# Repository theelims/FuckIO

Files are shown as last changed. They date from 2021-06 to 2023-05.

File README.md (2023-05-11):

# FuckIO
An opensource fucking machine, that is far superiour to anything on the market.
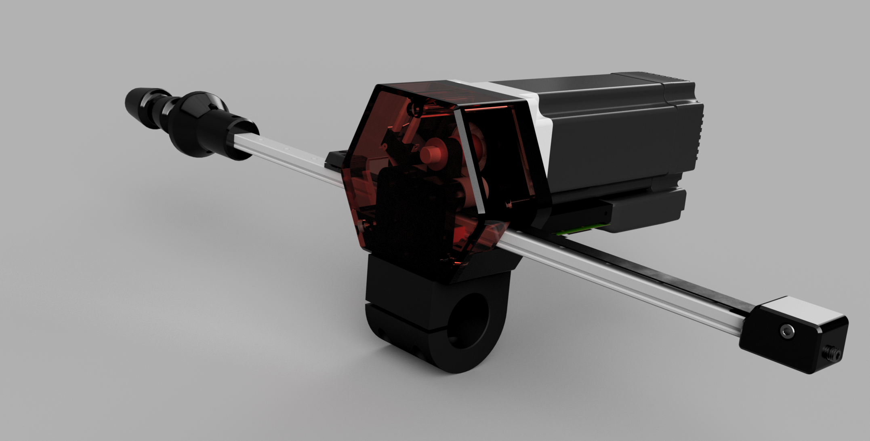
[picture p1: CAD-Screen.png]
Rendering


## Specs
* Easy to built just with a 3D-printer, screwdrivers and easy-to-source parts.
* Completely 3D-printable with easy to print parts and almost no supports. Also avoiding tight tolerances to make this accessable as possible. 
* Simple, yet verastile mechanics.
* Based on a linear position drive, not a crank mechanism.
* An 24V PWM output to drive external systems. Could be lube pumps, vibrators, etc.

## Mechanics
The mechanics is a direct derivative of an other open source project called OSSM. You can also find some informations about this build on their Discord.
https://github.com/KinkyMakers/OSSM-hardware

The motor mount is designed for a NEMA23 servo or stepper motor. Any motor fitting to this standart should work. 

### BOM
* iHSV57-30-18-36-... integrated servo motor from JMC
* 24V Power Brick Mean Well GST280A24-C6P 
* 40cm MGN12H linear rail
* 4x 605-2RS Z2 bearings
* Micro Switch
* GT2 20 Tooth Pulley for 8mm Axis and a 10mm belt
* GT2 belt with 10mm width
* Various M3 and M5 screws and nuts
* OSSM Ref Board from Research and Desire: https://shop.researchanddesire.com/collections/all/products/ossm-reference-board
* M5 Stack Remote Control from Ortlof: https://github.com/ortlof/OSSM-M5-Remote

## Control
### Firmware
The currently best firmware is the official OSSM firmware, or Ortlof's firmware for the M5 Remote https://github.com/ortlof/OSSM-M5-Remote

The firmware in the repository can only be used in conjunction with node-red.

The firmware uses the following projects:
* IotWebConf for WiFi provisioning: https://github.com/prampec/IotWebConf. Check the [end-user manual](https://github.com/prampec/IotWebConf/blob/master/doc/UsersManual.md) on how to use it.
* MQTT for communication: https://github.com/256dpi/arduino-mqtt Albeit SSL is not supported.
* My own library for generating the stroking motion: https://github.com/theelims/StrokeEngine/
* Which in turn uses https://github.com/gin66/FastAccelStepper for step generation and interfacing the servo motor.

### node-red
I've setup a node-red instance on my NAS to control FuckIO through MQTT messages. Have a look at the provided [flows.json](node-red/flows.json) to draw some inspiration from.

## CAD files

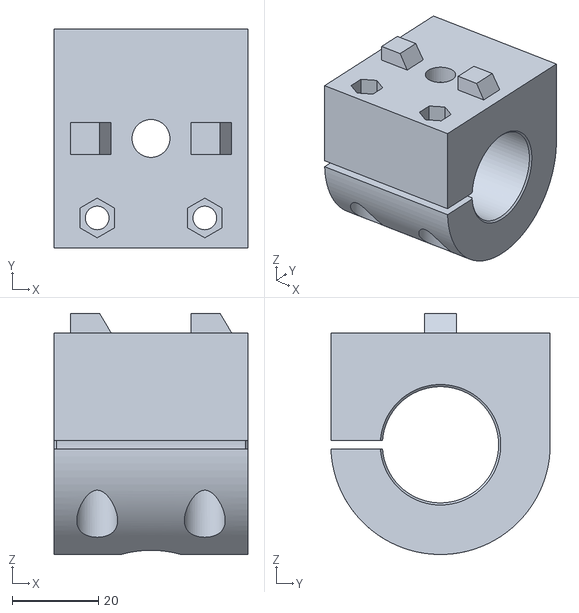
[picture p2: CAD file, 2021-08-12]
hardware/mechanics/3_4in Pipe Clamp.stl
45.0 x 51.0 x 56.0

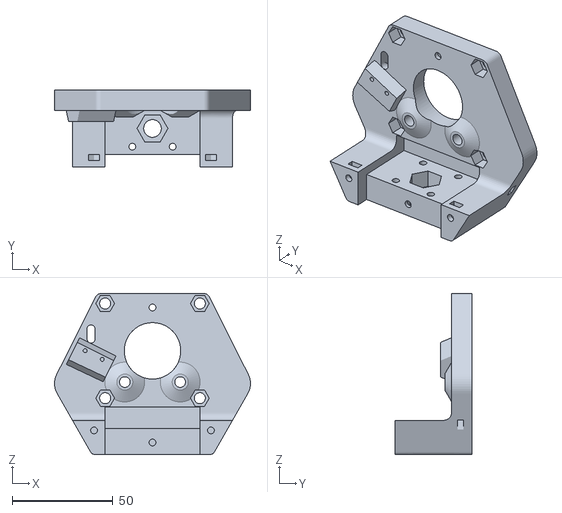
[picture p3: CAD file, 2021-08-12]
hardware/mechanics/Motor Mount.stl
97.3 x 38.0 x 80.0

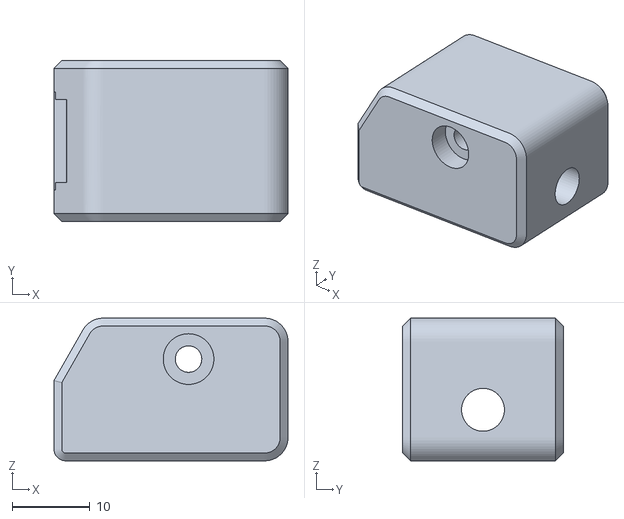
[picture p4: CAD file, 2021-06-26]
hardware/mechanics/Belt Tensioner.stl
30.0 x 20.6 x 18.3

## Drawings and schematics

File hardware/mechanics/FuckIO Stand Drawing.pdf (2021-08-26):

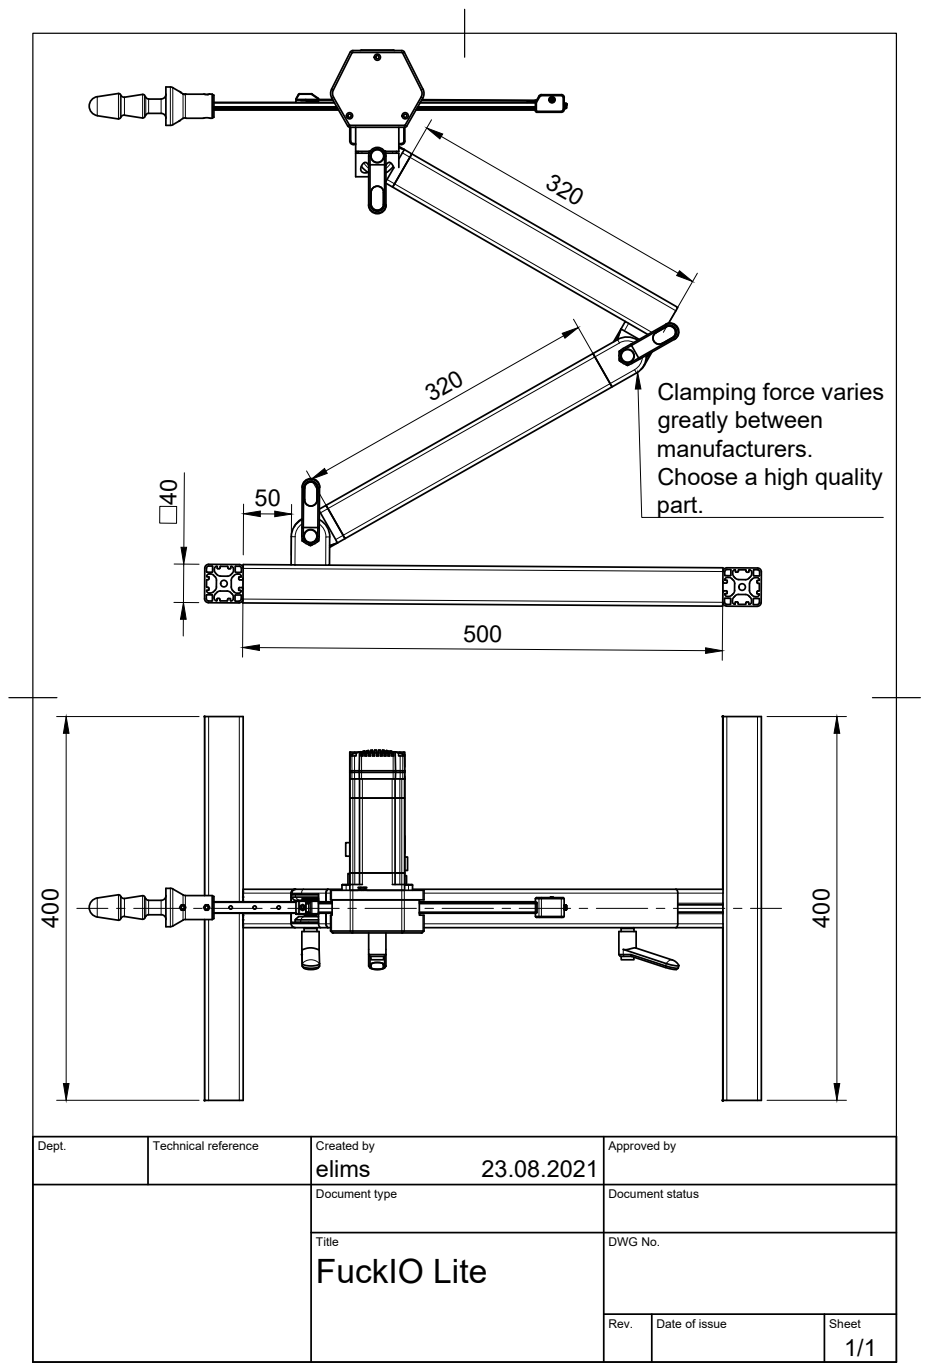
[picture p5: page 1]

Clamping force varies
greatly between
manufacturers.
Choose a high quality
part.

Dept. | Technical reference | Created by elims 23.08.2021 | Approved by

Document type | Document status

Title FuckIO Lite | DWG No.

Rev. | Date of issue | Sheet 1/1

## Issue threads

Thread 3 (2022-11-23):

ESP32 DevkitCv1 Compiling error

Nubi123bty, 2022-11-23:
hello, I am using an ESP32 and I am getting this error when compiling, I am new to using PIO and was wondering what I miss here.:
Compiling .pio\build\esp32\FrameworkArduino\esp32-hal-tinyusb.c.o
.pio/libdeps/esp32/FastAccelStepper/src/StepperISR_esp32.cpp: In function 'void apply_command(StepperQueue*, const queue_entry*)':
.pio/libdeps/esp32/FastAccelStepper/src/StepperISR_esp32.cpp:110:27: error: 'volatile struct mcpwm_timer_regs_t' has no member named 'status'; did you mean 'timer_status'?
   if (mcpwm->timer[timer].status.value <= 1) {  // mcpwm Timer is stopped ?
                           ^~~~~~
                           timer_status
.pio/libdeps/esp32/FastAccelStepper/src/StepperISR_esp32.cpp:111:25: error: 'volatile struct mcpwm_timer_regs_t' has no member named 'period'
     mcpwm->timer[timer].period.upmethod = 0;    // 0 = immediate update, 1 = TEZ
                         ^~~~~~
.pio/libdeps/esp32/FastAccelStepper/src/StepperISR_esp32.cpp:113:25: error: 'volatile struct mcpwm_timer_regs_t' has no member named 'period'
Compiling .pio\build\esp32\FrameworkArduino\esp32-hal-touch.c.o
     mcpwm->timer[timer].period.upmethod = 1;  // 0 = immediate update, 1 = TEZ
                         ^~~~~~
.pio/libdeps/esp32/FastAccelStepper/src/StepperISR_esp32.cpp:115:23: error: 'volatile struct mcpwm_timer_regs_t' has no member named 'period'
   mcpwm->timer[timer].period.period = ticks;
                       ^~~~~~
.pio/libdeps/esp32/FastAccelStepper/src/StepperISR_esp32.cpp:118:12: error: 'struct mcpwm_dev_t' has no member named 'channel'
     mcpwm->channel[timer].generator[0].utea = 1;
            ^~~~~~~
.pio/libdeps/esp32/FastAccelStepper/src/StepperISR_esp32.cpp:170:12: error: 'struct mcpwm_dev_t' has no member named 'channel'
     mcpwm->channel[timer].generator[0].utea = 2;
            ^~~~~~~
.pio/libdeps/esp32/FastAccelStepper/src/StepperISR_esp32.cpp: In function 'void init_stop(StepperQueue*)':
.pio/libdeps/esp32/FastAccelStepper/src/StepperISR_esp32.cpp:182:23: error: 'volatile struct mcpwm_timer_regs_t' has no member named 'mode'
   mcpwm->timer[timer].mode.start = 0;  // 0: stop at TEZ
                       ^~~~
.pio/libdeps/esp32/FastAccelStepper/src/StepperISR_esp32.cpp: In function 'void mcpwm0_isr_service(void*)':
.pio/libdeps/esp32/FastAccelStepper/src/StepperISR_esp32.cpp:223:20: error: 'volatile union mcpwm_int_st_reg_t' has no member named 'cmpr0_tea_int_st'
   if (mcpwm.int_st.cmpr##TIMER##_tea_int_st != 0) {   \
                    ^~~~
.pio/libdeps/esp32/FastAccelStepper/src/StepperISR_esp32.cpp:233:3: note: in expansion of macro 'MCPWM_SERVICE'
   MCPWM_SERVICE(MCPWM0, 0, 0);
   ^~~~~~~~~~~~~
.pio/libdeps/esp32/FastAccelStepper/src/StepperISR_esp32.cpp:223:20: error: 'volatile union mcpwm_int_st_reg_t' has no member named 'cmpr1_tea_int_st'
   if (mcpwm.int_st.cmpr##TIMER##_tea_int_st != 0) {   \
                    ^~~~
.pio/libdeps/esp32/FastAccelStepper/src/StepperISR_esp32.cpp:234:3: note: in expansion of macro 'MCPWM_SERVICE'
   MCPWM_SERVICE(MCPWM0, 1, 1);
   ^~~~~~~~~~~~~
.pio/libdeps/esp32/FastAccelStepper/src/StepperISR_esp32.cpp:223:20: error: 'volatile union mcpwm_int_st_reg_t' has no member named 'cmpr2_tea_int_st'
   if (mcpwm.int_st.cmpr##TIMER##_tea_int_st != 0) {   \
                    ^~~~
.pio/libdeps/esp32/FastAccelStepper/src/StepperISR_esp32.cpp:235:3: note: in expansion of macro 'MCPWM_SERVICE'
   MCPWM_SERVICE(MCPWM0, 2, 2);
   ^~~~~~~~~~~~~
.pio/libdeps/esp32/FastAccelStepper/src/StepperISR_esp32.cpp: In function 'void mcpwm1_isr_service(void*)':
.pio/libdeps/esp32/FastAccelStepper/src/StepperISR_esp32.cpp:223:20: error: 'volatile union mcpwm_int_st_reg_t' has no member named 'cmpr0_tea_int_st'
   if (mcpwm.int_st.cmpr##TIMER##_tea_int_st != 0) {   \
                    ^~~~
.pio/libdeps/esp32/FastAccelStepper/src/StepperISR_esp32.cpp:238:3: note: in expansion of macro 'MCPWM_SERVICE'
   MCPWM_SERVICE(MCPWM1, 0, 3);
   ^~~~~~~~~~~~~
.pio/libdeps/esp32/FastAccelStepper/src/StepperISR_esp32.cpp:223:20: error: 'volatile union mcpwm_int_st_reg_t' has no member named 'cmpr1_tea_int_st'
   if (mcpwm.int_st.cmpr##TIMER##_tea_int_st != 0) {   \
                    ^~~~
.pio/libdeps/esp32/FastAccelStepper/src/StepperISR_esp32.cpp:239:3: note: in expansion of macro 'MCPWM_SERVICE'
   MCPWM_SERVICE(MCPWM1, 1, 4);
   ^~~~~~~~~~~~~
.pio/libdeps/esp32/FastAccelStepper/src/StepperISR_esp32.cpp:223:20: error: 'volatile union mcpwm_int_st_reg_t' has no member named 'cmpr2_tea_int_st'
   if (mcpwm.int_st.cmpr##TIMER##_tea_int_st != 0) {   \
                    ^~~~
.pio/libdeps/esp32/FastAccelStepper/src/StepperISR_esp32.cpp:240:3: note: in expansion of macro 'MCPWM_SERVICE'
   MCPWM_SERVICE(MCPWM1, 2, 5);
   ^~~~~~~~~~~~~
.pio/libdeps/esp32/FastAccelStepper/src/StepperISR_esp32.cpp: In member function 'void StepperQueue::init(uint8_t, uint8_t)':
.pio/libdeps/esp32/FastAccelStepper/src/StepperISR_esp32.cpp:288:55: error: 'PERIPH_PWM0_MODULE' was not declared in this scope
     periph_module_enable(mcpwm_unit == MCPWM_UNIT_0 ? PERIPH_PWM0_MODULE
                                                       ^~~~~~~~~~~~~~~~~~
.pio/libdeps/esp32/FastAccelStepper/src/StepperISR_esp32.cpp:288:55: note: suggested alternative: 'PERIPHS_IO_MUX_MTDO_U'
     periph_module_enable(mcpwm_unit == MCPWM_UNIT_0 ? PERIPH_PWM0_MODULE
                                                       ^~~~~~~~~~~~~~~~~~
                                                       PERIPHS_IO_MUX_MTDO_U
.pio/libdeps/esp32/FastAccelStepper/src/StepperISR_esp32.cpp:289:55: error: 'PERIPH_PWM1_MODULE' was not declared in this scope
                                                     : PERIPH_PWM1_MODULE);
                                                       ^~~~~~~~~~~~~~~~~~
.pio/libdeps/esp32/FastAccelStepper/src/StepperISR_esp32.cpp:289:55: note: suggested alternative: 'PERIPHS_IO_MUX_MTDO_U'
                                                     : PERIPH_PWM1_MODULE);
                                                       ^~~~~~~~~~~~~~~~~~
                                                       PERIPHS_IO_MUX_MTDO_U
.pio/libdeps/esp32/FastAccelStepper/src/StepperISR_esp32.cpp:288:5: error: 'periph_module_enable' was not declared in this scope
     periph_module_enable(mcpwm_unit == MCPWM_UNIT_0 ? PERIPH_PWM0_MODULE
     ^~~~~~~~~~~~~~~~~~~~
.pio/libdeps/esp32/FastAccelStepper/src/StepperISR_esp32.cpp:288:5: note: suggested alternative: 'esp_intr_enable'
     periph_module_enable(mcpwm_unit == MCPWM_UNIT_0 ? PERIPH_PWM0_MODULE
     ^~~~~~~~~~~~~~~~~~~~
     esp_intr_enable
.pio/libdeps/esp32/FastAccelStepper/src/StepperISR_esp32.cpp:297:20: error: 'volatile union mcpwm_clk_cfg_reg_t' has no member named 'prescale'
     mcpwm->clk_cfg.prescale = 5 - 1;
                    ^~~~~~~~
.pio/libdeps/esp32/FastAccelStepper/src/StepperISR_esp32.cpp:299:12: error: 'struct mcpwm_dev_t' has no member named 'timer_sel'; did you mean 'timer'?
Compiling .pio\build\esp32\FrameworkArduino\esp32-hal-uart.c.o
     mcpwm->timer_sel.operator0_sel = 0;  // timer 0 is input for operator 0
            ^~~~~~~~~
            timer
.pio/libdeps/esp32/FastAccelStepper/src/StepperISR_esp32.cpp:300:12: error: 'struct mcpwm_dev_t' has no member named 'timer_sel'; did you mean 'timer'?
     mcpwm->timer_sel.operator1_sel = 1;  // timer 1 is input for operator 1
            ^~~~~~~~~
            timer
.pio/libdeps/esp32/FastAccelStepper/src/StepperISR_esp32.cpp:301:12: error: 'struct mcpwm_dev_t' has no member named 'timer_sel'; did you mean 'timer'?
     mcpwm->timer_sel.operator2_sel = 2;  // timer 2 is input for operator 2
            ^~~~~~~~~
            timer
.pio/libdeps/esp32/FastAccelStepper/src/StepperISR_esp32.cpp:303:23: error: 'volatile struct mcpwm_timer_regs_t' has no member named 'period'
   mcpwm->timer[timer].period.upmethod = 1;  // 0 = immediate update, 1 = TEZ
                       ^~~~~~
.pio/libdeps/esp32/FastAccelStepper/src/StepperISR_esp32.cpp:304:23: error: 'volatile struct mcpwm_timer_regs_t' has no member named 'period'
   mcpwm->timer[timer].period.prescale = TIMER_PRESCALER;
                       ^~~~~~
.pio/libdeps/esp32/FastAccelStepper/src/StepperISR_esp32.cpp:305:23: error: 'volatile struct mcpwm_timer_regs_t' has no member named 'period'
   mcpwm->timer[timer].period.period = 400;  // Random value
                       ^~~~~~
.pio/libdeps/esp32/FastAccelStepper/src/StepperISR_esp32.cpp:306:23: error: 'volatile struct mcpwm_timer_regs_t' has no member named 'mode'
   mcpwm->timer[timer].mode.mode = 3;        // 3=up/down counting
                       ^~~~
.pio/libdeps/esp32/FastAccelStepper/src/StepperISR_esp32.cpp:307:23: error: 'volatile struct mcpwm_timer_regs_t' has no member named 'mode'
   mcpwm->timer[timer].mode.start = 0;       // 0: stop at TEZ
                       ^~~~
.pio/libdeps/esp32/FastAccelStepper/src/StepperISR_esp32.cpp:310:23: error: 'volatile struct mcpwm_timer_regs_t' has no member named 'sync'
   mcpwm->timer[timer].sync.timer_phase = 0;  // prepare value of 0
                       ^~~~
.pio/libdeps/esp32/FastAccelStepper/src/StepperISR_esp32.cpp:311:23: error: 'volatile struct mcpwm_timer_regs_t' has no member named 'sync'
   mcpwm->timer[timer].sync.in_en = 1;        // enable sync
                       ^~~~
.pio/libdeps/esp32/FastAccelStepper/src/StepperISR_esp32.cpp:312:23: error: 'volatile struct mcpwm_timer_regs_t' has no member named 'sync'
Compiling .pio\build\esp32\FrameworkArduino\firmware_msc_fat.c.o
   mcpwm->timer[timer].sync.sync_sw ^= 1;     // force a sync
                       ^~~~
.pio/libdeps/esp32/FastAccelStepper/src/StepperISR_esp32.cpp:313:23: error: 'volatile struct mcpwm_timer_regs_t' has no member named 'sync'
   mcpwm->timer[timer].sync.in_en = 0;        // disable sync
                       ^~~~
.pio/libdeps/esp32/FastAccelStepper/src/StepperISR_esp32.cpp:315:10: error: 'struct mcpwm_dev_t' has no member named 'channel'
   mcpwm->channel[timer].cmpr_cfg.a_upmethod = 0;     // 0 = immediate update
          ^~~~~~~
.pio/libdeps/esp32/FastAccelStepper/src/StepperISR_esp32.cpp:316:10: error: 'struct mcpwm_dev_t' has no member named 'channel'
   mcpwm->channel[timer].cmpr_value[0].cmpr_val = 1;  // set compare value A
          ^~~~~~~
.pio/libdeps/esp32/FastAccelStepper/src/StepperISR_esp32.cpp:317:10: error: 'struct mcpwm_dev_t' has no member named 'channel'
   mcpwm->channel[timer].generator[0].val = 0;   // clear all trigger actions
          ^~~~~~~
.pio/libdeps/esp32/FastAccelStepper/src/StepperISR_esp32.cpp:318:10: error: 'struct mcpwm_dev_t' has no member named 'channel'
   mcpwm->channel[timer].generator[1].val = 0;   // clear all trigger actions
          ^~~~~~~
.pio/libdeps/esp32/FastAccelStepper/src/StepperISR_esp32.cpp:319:10: error: 'struct mcpwm_dev_t' has no member named 'channel'
   mcpwm->channel[timer].generator[0].dtep = 1;  // low at period
          ^~~~~~~
.pio/libdeps/esp32/FastAccelStepper/src/StepperISR_esp32.cpp:320:10: error: 'struct mcpwm_dev_t' has no member named 'channel'
   mcpwm->channel[timer].db_cfg.val = 0;         // edge delay disabled
          ^~~~~~~
.pio/libdeps/esp32/FastAccelStepper/src/StepperISR_esp32.cpp:321:10: error: 'struct mcpwm_dev_t' has no member named 'channel'
   mcpwm->channel[timer].carrier_cfg.val = 0;    // carrier disabled
          ^~~~~~~
.pio/libdeps/esp32/FastAccelStepper/src/StepperISR_esp32.cpp: In member function 'bool StepperQueue::isRunning()':
Compiling .pio\build\esp32\FrameworkArduino\libb64\cdecode.c.o
.pio/libdeps/esp32/FastAccelStepper/src/StepperISR_esp32.cpp:367:27: error: 'volatile struct mcpwm_timer_regs_t' has no member named 'status'; did you mean 'timer_status'?
   if (mcpwm->timer[timer].status.value > 1) {
                           ^~~~~~
                           timer_status
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

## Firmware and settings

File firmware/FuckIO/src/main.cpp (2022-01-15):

/**
 *   FuckIO Firmware for ESP32
 *   Use MQTT messages to control all built-in motion patterns
 *   https://github.com/theelims/FuckIO 
 *
 * Copyright (C) 2022 theelims <elims@gmx.net>
 *
 * This software may be modified and distributed under the terms
 * of the MIT license.  See the LICENSE file for details.
 */

#include <Arduino.h>
#include <config.h>
#include <housekeeping.h>
#include <StrokeEngine.h>

/*#################################################################################################
##
##    G L O B A L    D E F I N I T I O N S   &   D E C L A R A T I O N S
##
##################################################################################################*/

// Calculation Aid:
#define STEP_PER_REV      2000      // How many steps per revolution of the motor (S1 off, S2 on, S3 on, S4 off)
#define PULLEY_TEETH      20        // How many teeth has the pulley
#define BELT_PITCH        2         // What is the timing belt pitch in mm
#define MAX_RPM           3000.0    // Maximum RPM of motor
#define STEP_PER_MM       STEP_PER_REV / (PULLEY_TEETH * BELT_PITCH)
#define MAX_SPEED         (MAX_RPM / 60.0) * PULLEY_TEETH * BELT_PITCH

static motorProperties servoMotor {  
  .maxSpeed = MAX_SPEED,                
  .maxAcceleration = 100000,      
  .stepsPerMillimeter = STEP_PER_MM,   
  .invertDirection = true,      
  .enableActiveLow = true,      
  .stepPin = SERVO_PULSE,              
  .directionPin = SERVO_DIR,          
  .enablePin = SERVO_ENABLE              
};

static machineGeometry strokingMachine = {
  .physicalTravel = 160.0,       
  .keepoutBoundary = 5.0      
};

static endstopProperties endstop = {
  .homeToBack = true,    
  .activeLow = true,          
  .endstopPin = SERVO_ENDSTOP,
  .pinMode = INPUT
};

StrokeEngine Stroker;

String getPatternJSON();


/*#################################################################################################
##
##    C A L L B A C K S
##
##################################################################################################*/

void homingNotification(bool isHomed) {
  if (isHomed) {
    mqttNotify("Found home - Ready to rumble!");
  } else {
    mqttNotify("Homing failed!");
  }
}

void strokeEngineTelemetry(float position, float speed, bool clipping) {
  mqttPublish("/diagnose", 
    "{\"position\":" + String(position * 10, 1) + 
    ",\"speed\":" + String(speed, 1) + 
    ",\"clipping\":" + String(clipping) + "}");
}

void controlSpeed(String payload) {
  Serial.println("Speed: " + String(payload));
  Stroker.setSpeed(payload.toFloat(), true);
}

void controlDepth(String payload) {
  Serial.println("Depth: " + String(payload));
  Stroker.setDepth(payload.toFloat(), true);
}

void controlStroke(String payload) {
  Serial.println("Stroke: " + String(payload));
  Stroker.setStroke(payload.toFloat(), true);
}

void controlSensation(String payload) {
  Serial.println("Sensation: " + payload);
  Stroker.setSensation(payload.toFloat(), true);
}

void receiveCommand(String payload) {
  Serial.println("Command: " + payload);
  if (payload.equals("start")) {
    Stroker.startPattern();
  }
  if (payload.equals("stop")) {
    Stroker.stopMotion();
  }
  if (payload.equals("retract")) {
    Stroker.moveToMin();
  }
  if (payload.equals("extend")) {
    Stroker.moveToMax();
  }
  if (payload.equals("setup")) {
    Stroker.setupDepth(10.0, true);
  }
  if (payload.equals("disable")) {
    Stroker.disable();
  }
  if (payload.equals("home")) {
    Stroker.enableAndHome(&endstop, homingNotification);
  }
  if (payload.equals("patternlist")) {
    mqttPublish("/config", getPatternJSON());
  }
}

void receivePWM(String payload) {
  Serial.println("PWM: " + payload);

  // Convert payload to int
  int pulseWidth = payload.toInt();

  // constrain to 8-bit value range
  pulseWidth = constrain(pulseWidth, 0, 255);

  // set PWM
  ledcWrite(0, 0);
}

void receivePattern(String payload) {
  Serial.println("Pattern Index: " + String(payload));
  Stroker.setPattern(payload.toInt(), true);
}

/*#################################################################################################
##
##    T A S K S
##
##################################################################################################*/

// None

/*#################################################################################################
##
##    I S R ' S
##
##################################################################################################*/

// None

/*#################################################################################################
##
##    M A I N   P R O G R A M
##
##################################################################################################*/

void setup() 
{
  // Handle WiFi, Provisioning by IoTWebConf, MQTT connection & power in the background
  beginHousework();

  // Register callbacks for all MQTT subscriptions
  mqttSubscribe("/speed", controlSpeed);
  mqttSubscribe("/depth", controlDepth);
  mqttSubscribe("/stroke", controlStroke);
  mqttSubscribe("/sensation", controlSensation);
  mqttSubscribe("/command", receiveCommand);
  mqttSubscribe("/pattern", receivePattern);
  mqttSubscribe("/pwm", receivePWM);

  // Set PWM output with 8bit resolution and 5kHz
  ledcSetup(0, 5000, 8);
  ledcAttachPin(PWM, 0);
  ledcWrite(0, 0);

  // Wait for MQTT to be available
  while (!mqttConnected()) {
    delay(1000);
  }

  // Wait a little bit for topic subscriptions to complete
  delay(1000);

  // Setup Stroke Engine
  Stroker.begin(&strokingMachine, &servoMotor);
  Stroker.registerTelemetryCallback(strokeEngineTelemetry);
  Stroker.enableAndHome(&endstop, homingNotification);

  // Send available patterns as JSON
  mqttPublish("/config", getPatternJSON());

}

void loop() 
{
  vTaskDelete(NULL);
}

/*#################################################################################################
##
##    O T H E R   F U N C T I O N S
##
##################################################################################################*/

String getPatternJSON() {
    String JSON = "[{\"";
    for (size_t i = 0; i < Stroker.getNumberOfPattern(); i++) {
        JSON += String(Stroker.getPatternName(i));
        JSON += "\": ";
        JSON += String(i, DEC);
        if (i < Stroker.getNumberOfPattern() - 1) {
            JSON += "},{\"";
        } else {
            JSON += "}]";
        }
    }
    Serial.println(JSON);
    return JSON;
}

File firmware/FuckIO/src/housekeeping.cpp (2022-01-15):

#include <Arduino.h>
#include <housekeeping.h>
#include <LinkedList.h>
#include "config.h"
#include <MQTT.h>
#include <IotWebConf.h>
#include <IotWebConfUsing.h> // This loads aliases for easier class names.
#include <IotWebConfESP32HTTPUpdateServer.h>

// -- Initial name of the Thing. Used e.g. as SSID of the own Access Point.
String ChipId = String((uint32_t)ESP.getEfuseMac(), HEX);
// String thingName = String(THINGNAME) + "-" + ChipId;
String thingName = String(THINGNAME);

// -- Initial password to connect to the Thing, when it creates an own Access Point.
const char wifiInitialApPassword[] = INITIAL_AP_PASSWORD;

// -- Method declarations.
void handleRoot();
bool connectMqtt();
bool connectMqttOptions();
void doHousework(void * parameter);
void reportRSSI(void * parameter);

// -- Callback methods.
void wifiConnected();
void configSaved();
bool formValidator(iotwebconf::WebRequestWrapper* webRequestWrapper);
void mqttMessageReceived(String &topic, String &payload);

DNSServer dnsServer;
WebServer server(80);
HTTPUpdateServer httpUpdater;
WiFiClient net;
MQTTClient mqttClient(256);

char mqttServerValue[STRING_LEN];
char mqttUserNameValue[STRING_LEN];
char mqttUserPasswordValue[STRING_LEN];

IotWebConf iotWebConf(thingName.c_str(), &dnsServer, &server, wifiInitialApPassword, CONFIG_VERSION);
IotWebConfParameterGroup mqttGroup = IotWebConfParameterGroup("mqtt", "MQTT configuration");
IotWebConfTextParameter mqttServerParam = IotWebConfTextParameter("MQTT server", "mqttServer", mqttServerValue, STRING_LEN);
IotWebConfTextParameter mqttUserNameParam = IotWebConfTextParameter("MQTT user", "mqttUser", mqttUserNameValue, STRING_LEN);
IotWebConfPasswordParameter mqttUserPasswordParam = IotWebConfPasswordParameter("MQTT password", "mqttPass", mqttUserPasswordValue, STRING_LEN);

bool needMqttConnect = false;
bool needReset = false;

unsigned long lastMqttConnectionAttempt = 0;

LinkedList<MQTTSubscriptionResponse*> MQTTResponseList = LinkedList<MQTTSubscriptionResponse*>();

char* generateMqttTopic(char *topicSuffix)
{
    static char connectTopic[STRING_LEN];
    strcpy(connectTopic, iotWebConf.getThingName());
    strcat(connectTopic, topicSuffix);
    return connectTopic;
}

void beginHousework()
{

    pinMode(BUTTON_PIN, INPUT_PULLUP); // Shady workaround for IoTWebConf for ESP32 Issue 124

#if defined(POWER_HOLD)
    pinMode(POWER_HOLD, OUTPUT);
    digitalWrite(POWER_HOLD, LOW);
#endif

    Serial.begin(115200); 
    Serial.println();
    Serial.println("Starting up...");

    mqttGroup.addItem(&mqttServerParam);
    mqttGroup.addItem(&mqttUserNameParam);
    mqttGroup.addItem(&mqttUserPasswordParam);

    iotWebConf.setStatusPin(STATUS_PIN);
    iotWebConf.setConfigPin(BUTTON_PIN); //FIXME Bug in IoTWebConf for ESP32: (Github Issue 124) 
    iotWebConf.skipApStartup();
    iotWebConf.addParameterGroup(&mqttGroup);
    iotWebConf.setConfigSavedCallback(&configSaved);
    iotWebConf.setFormValidator(&formValidator);
    iotWebConf.setWifiConnectionCallback(&wifiConnected);
    iotWebConf.setupUpdateServer(
        [](const char* updatePath) { httpUpdater.setup(&server, updatePath); },
        [](const char* userName, char* password) { httpUpdater.updateCredentials(userName, password); });

    // -- Initializing the configuration.
    bool validConfig = iotWebConf.init();
    if (!validConfig)
    {
        mqttServerValue[0] = '\0';
        mqttUserNameValue[0] = '\0';
        mqttUserPasswordValue[0] = '\0';
    }

    // -- Set up required URL handlers on the web server.
    server.on("/", handleRoot);
    server.onNotFound([](){ iotWebConf.handleNotFound(); });

    mqttClient.begin(mqttServerValue, net);
    mqttClient.onMessage(mqttMessageReceived);
    
    Serial.println("Ready.");

#if defined(POWER_HOLD)
    //Subscribe to a switch off topic and add to link list 
    mqttSubscribe("/goodbye", goodbye);
#endif

    xTaskCreatePinnedToCore(
        doHousework, // Function that should be called
        "Housekeeping task",    // Name of the task (for debugging)
        4096,            // Stack size (bytes)
        NULL,            // Parameter to pass
        10,              // Run task with modest priority
        NULL,            // Task handle
        0                // Keep on protocol core
    );

      // Create task to report RSSI periodically as MQTT message
    xTaskCreatePinnedToCore(
        reportRSSI,      // Function that should be called
        "Report RSSI",   // Name of the task (for debugging)
        2048,            // Stack size (bytes)
        NULL,            // Parameter to pass
        2,               // Task priority
        NULL,            // Task handle
        0                // Keep on protocol core
    );

}
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

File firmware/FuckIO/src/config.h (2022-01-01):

#pragma once

// Pin Definitions
#define SERVO_PULSE       4
#define SERVO_DIR         16
#define SERVO_ENABLE      17
#define SERVO_ENDSTOP     25
#define SERVO_ALARM       26
#define PWM               21
#define STATUS_PIN        22        // IoTWebConf WiFi Status Pin
#define BUTTON_PIN        23        // IoTWebConf Button (for restoring default WiFi AP)

// Housekeeping Settings:
#define CONFIG_VERSION      "fio00.01"      // Version of the configuration
#define THINGNAME           "FuckIO"        // Inital Thing Name, also used as hostname, MQTT topic root and AP name
#define INITIAL_AP_PASSWORD "smrtTHNG32"    // Default password of the AP, must be changed on first start, 
                                            // but can be restored by the WiFi button
#define SERIAL_BAUDS         115200         // Default baud rate for serial communication over USB
#define RSSI_UPDATES         500            // Intervall in ms at which the RSSI value should be send as MQTT message
#define STRING_LEN           64             // Bytes used to initialize char array. No path, topic, name, etc. should exceed this value

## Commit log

2021-06-23 Delete PCB
    PCB was a failure and didn't work out. Going for as EPS32 solution.
    [FuckIO_REV00.brd, FuckIO_REV00.sch]
2021-06-23 Delete firmware/FuckIO directory
    SAMD21 does not really work. Going for an ESP32 solution with fastaccelsteller library.
2021-06-23 Update README.md
    Recommended OSSM board and firmware.
2021-06-26 Updated belt tensioner
2021-06-26 Current version with updated belt tension system
2021-08-12 Moving everything to ESP32
    [3_4in Pipe Clamp.stl, Belt Tensioner.stl, Motor Mount.stl]
2021-08-12 moved Endstop Pin to lib
2021-08-15 Added electronics
    [FuckIO_REV01.brd, FuckIO_REV01.sch]
2021-08-26 Bugfix: Stacksize Housekeeping Task
    [housekeeping.cpp]
2023-05-11 Electronics is obsolet
    [FuckIO_REV01.brd, FuckIO_REV01.sch]
